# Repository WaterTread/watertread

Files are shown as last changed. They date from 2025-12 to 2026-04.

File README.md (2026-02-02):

# WaterTread



WaterTread is an open, tread-based hydrodynamic energy conversion system designed to harvest kinetic energy from flowing water using a controlled, blade-driven linear motion instead of a traditional rotating turbine.

The system is optimized for low- to moderate-flow environments and emphasizes simplicity, scalability, and containerized deployment.

[See 3D-model](https://watertreadweb.vercel.app/)

---

## Concept Overview

Unlike conventional hydrokinetic turbines, WaterTread uses a dual-tread mechanism with actively oriented blades that engage the water flow over an extended linear capture path.

Key principles:

- Multiple blades are engaged simultaneously
- Blades operate in alternating high-drag (capture) and low-drag (return) states
- Motion is driven purely by hydrodynamic forces
- Torque delivery is smooth and continuous
- Mechanical simplicity enables modular scaling

This approach reduces return-path losses and improves blade utilization compared to point-based rotating systems.

---

## Key Features

- Linear tread-based energy capture (non-rotor design)
- Actively controlled blade orientation using cams and followers
- High torque output at low flow velocities
- Low-drag, protected return path
- Modular and scalable architecture
- Designed to fit within standard ISO shipping containers
- Suitable for rivers, channels, and low-head flow environments

---

## Repository Structure

```
docs/                 Technical documentation (GitHub Pages)
models/               3D models and mechanical designs
  - prototype/        Early prototype models
  - 1.0/              Versioned production-ready designs
parts/                Parts lists and component specifications
images/               Diagrams, renders, and reference images
LICENSE               Non-commercial open license
COMMERCIAL.md         Commercial licensing terms
README.md             This file
```

---

## Licensing

### Non-Commercial Use

This project is released under the Creative Commons Attribution–NonCommercial–ShareAlike 4.0 (CC BY-NC-SA 4.0) license.

You are free to:

- Study and experiment with the design
- Build non-commercial prototypes
- Modify and improve the design
- Share derivative works under the same license

Commercial use is not permitted under this license.

---

### Commercial Use

Any commercial use — including manufacturing, deployment for power generation, or integration into commercial products — requires a separate license.

Commercial licensing is intentionally designed to be flexible, accessible, and affordable.

Royalty-based licenses are expected to be modest and competitive, often capped around approximately 1% of generated revenue, depending on project scope.

See [COMMERCIAL.md](COMMERCIAL.md) for details.

---

## Project Status

WaterTread is currently in an active design and prototyping phase.

- Mechanical concepts validated at prototype scale
- Detailed component documentation in progress
- Versioned 3D models under development
- Contributions and feedback are welcome

---

## Contributing

Contributions are welcome in the form of:

- Design feedback and reviews
- Mechanical or hydrodynamic improvements
- Simulation and analysis
- Documentation improvements
- Prototype testing insights

Please respect the non-commercial license terms when contributing.

---

## Disclaimer

This project is provided as-is, without warranty of any kind.
The author assumes no liability for the use, modification, or deployment of the design.

---

## Contact

For questions, collaboration, or commercial licensing inquiries:

Project Maintainer:
Keijo Mukku
keijo.mukku@gmail.com

Early-stage pilots, research collaborations, and first commercial deployments are especially welcome.

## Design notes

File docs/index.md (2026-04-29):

# WaterTread Documentation



Welcome to the WaterTread technical documentation.

WaterTread is an experimental open-flow hydrokinetic energy harvester concept designed to explore whether a staggered, three-dimensional moving blade field can extract useful energy from shallow flowing water without requiring a dam, closed pipe, or highly obstructive channel.

This documentation describes the operating principles, mechanical design, hydrodynamic assumptions, system-level behavior, and key validation questions behind the WaterTread concept.

## Contents

- [Project Considerations](considerations.md)
- [Hydrodynamic Operating Principle](hydrodynamics.md)
- [Blade Motion Cycle](blade_motion_cycle.md)
- [Power Transmission Overview](power_transmission.md)
- [System Efficiency Considerations](efficiency.md)
- [Profitability and ROI](profitability.md)

## Recommended Reading Order

If you are new to the project, start with:

1. [Project Considerations](considerations.md)  
   Defines the core hypothesis, engineering assumptions, risks, validation criteria, and early stop conditions.

2. [Hydrodynamic Operating Principle](hydrodynamics.md)  
   Explains how WaterTread is intended to interact with open-channel water flow.

3. [Blade Motion Cycle](blade_motion_cycle.md)  
   Describes the capture and return phases of the blade movement, including the low-drag return orientation.

4. [System Efficiency Considerations](efficiency.md)  
   Discusses the main factors that affect net power, including return drag, wake interaction, mechanical losses, and flow blockage.

For detailed component documentation, see the [`/parts`](../parts) directory.

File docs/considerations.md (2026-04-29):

# WaterTread Considerations

This document captures the current engineering reasoning, hypotheses, risks, validation needs, and development strategy for the WaterTread concept.

WaterTread is an early-stage hydrokinetic energy harvesting concept. It is not yet claimed to be more efficient than conventional hydrokinetic turbines, nor is it claimed to be commercially viable. The purpose of this document is to define what must be true for the concept to be worth continued development, and how those assumptions can be tested.

---

## 1. Core idea

WaterTread is an open-flow hydrokinetic energy harvester concept intended to extract useful energy from moving water without using a dam, closed pipe, or strongly obstructive channel.

The concept uses a moving tread-like mechanism carrying multiple blades. In the power-producing portion of the cycle, the blades present a large face to the water flow. In the return portion of the cycle, the blades rotate or travel edge-on to the flow, reducing return drag.

A key distinction from simple drag devices is that the blades are not merely arranged as a single flat row. The WaterTread concept aims to form a staggered, three-dimensional blade field, where partially overlapping blades interact with the flow across width, height, and depth.

The central design question is:

> Can a staggered, three-dimensional moving blade field extract useful net power from shallow open-channel flow while keeping return drag, blockage, ecological disruption, and mechanical losses acceptably low?

---

## 2. Core hypothesis

The central hypothesis is:

> Partially overlapping blades, arranged in a three-dimensional moving field, can interact with a larger shallow-flow volume than a single rotor disk or single flat blade, while returning edge-on to the flow to minimize return drag.

A more detailed version:

> A staggered 3D blade field may be able to produce higher useful force in shallow, wide, open flows by allowing multiple blades to engage different portions of the incoming flow, rather than forcing all energy extraction through a single circular rotor disk or a single flat capture surface.

This hypothesis is especially relevant to shallow and wide water flows, where conventional propeller-style or axial-flow rotors may be limited by available depth, rotor diameter, safety, debris, and ecological concerns.

---

## 3. What WaterTread is not yet claiming

WaterTread should not currently claim:

- that it is universally more efficient than hydrokinetic turbines;
- that it can exceed known physical limits for open-flow energy extraction;
- that it can collect energy without affecting the flow;
- that length alone creates additional free energy;
- that CFD, AI, or geometry generation alone can validate the concept;
- that the concept is commercially viable before physical or numerical validation.

A better and more defensible claim is:

> WaterTread explores whether a slow-moving, staggered, three-dimensional blade field can provide useful net power in shallow open-flow environments where conventional rotors may be limited by depth, safety, debris, maintenance, or ecological concerns.

---

## 4. Why not dams?

Dams are highly effective at extracting energy from water because they create hydraulic head: a difference in water height and pressure. This allows large amounts of gravitational potential energy to be converted into controlled high-power flow through turbines.

However, dams can cause major ecological and social impacts, including:

- blocked fish migration;
- altered sediment transport;
- changed river temperature and oxygen dynamics;
- disrupted seasonal flow patterns;
- habitat fragmentation;
- flooding of upstream land;
- significant permitting and infrastructure burden.

WaterTread is not intended to compete with the raw efficiency of large dam-based hydropower. Instead, it belongs conceptually to the hydrokinetic category: extracting energy from naturally moving water without requiring major hydraulic head, impoundment, or river closure.

The challenge is that hydrokinetic devices usually have much lower available energy density than dam-based systems.

---

## 5. Open-flow energy limitation

In open-flow systems, energy is extracted from the kinetic energy of moving water.

A useful first-order estimate of available kinetic power is:

```text
P_available ≈ 0.5 × rho × A × v^3
```

Where:

- `rho` is water density, approximately 1000 kg/m³;
- `A` is the effective flow area interacting with the device;
- `v` is the water velocity.

The velocity term is cubed. This means water speed is extremely important.

Example:

```text
A = 0.1 m²

v = 0.5 m/s  →  P_available ≈ 6.25 W
v = 1.0 m/s  →  P_available ≈ 50 W
v = 2.0 m/s  →  P_available ≈ 400 W
```

These values are before conversion losses. Real electrical output would be lower.

This means slow water contains surprisingly little useful power unless the device interacts with a large enough flow area or is placed in sufficiently fast current.

---

## 6. Important physical truth

If a device extracts energy from flowing water, it must affect the flow.

A completely invisible, zero-obstruction device cannot extract energy. Energy extraction requires changing the water's momentum, pressure field, or velocity field.

Therefore, the goal is not:

> Extract energy without affecting the flow at all.

The realistic goal is:

> Extract useful energy while minimizing harmful obstruction, ecological disruption, turbulence, debris accumulation, and flow blockage.

A better optimization target may be:

```text
maximize useful net power per ecological disturbance
```

or:

```text
maximize net power per blocked flow area
```

rather than simply maximizing raw power.

---

## 7. Comparison against rotors

Conventional hydrokinetic rotors are strong competitors. A well-designed lift-based rotor can be highly efficient because its blades can continuously produce useful torque without a separate return stroke.

This is an important difference:

```text
Rotor:
  - lift-based
  - blades can produce useful torque throughout rotation
  - no separate high-drag return side
  - mechanically compact
  - often efficient per swept area

Drag/tread device:
  - typically requires a power side and a return side
  - must minimize return drag
  - can suffer from mechanical complexity
  - may be less efficient per swept area
```

WaterTread's possible advantage is not necessarily pure hydrodynamic efficiency. Its stronger possible niche is:

- shallow water;
- wide but low-depth flow;
- slow and visible moving parts;
- easier access and maintenance;
- modular layout;
- potentially lower fish-strike risk than fast rotor tips;
- better use of a rectangular shallow flow envelope;
- less need for a deep circular swept area.

A fair comparison should not be WaterTread versus one arbitrary small rotor. It should be:

> WaterTread versus the best realistic rotor or multi-rotor arrangement that fits the same width, height, depth, blockage, ecological, and cost constraints.

---

## 8. Proposed advantage over rotor-like structures

A rotor collects energy from a swept disk area. Mechanically, it is compact and local in the stream.

WaterTread may instead distribute energy extraction across a longer and more volumetric interaction region.

The proposed advantage is:

> WaterTread may use a staggered 3D blade field to interact with a shallow flow volume across width, height, and depth, instead of requiring a deep circular rotor disk.

This may be beneficial where the available flow is:

- shallow;
- wide;
- debris-prone;
- ecologically sensitive;
- unsuitable for large-diameter rotors;
- better served by a slow-moving, modular, serviceable mechanism.

However, the fact that the device is longer in the flow direction does not automatically mean it accesses proportionally more energy. The key question is whether rear or overlapping blades receive sufficiently fresh flow, or whether they are mostly shadowed by the wake of upstream blades.

---

## 9. Staggered 3D blade field hypothesis

The most important WaterTread-specific hypothesis is not merely that the device is long.

The stronger hypothesis is:

> A staggered and partially overlapping blade field can reduce wake shadowing and allow multiple blades to extract energy from different portions of the flow volume.

This can be described as:

```text
3D staggered blade field
```

or:

```text
staggered volumetric blade array
```

Potential benefits:

- larger effective interaction volume;
- multiple blades in useful capture orientation at once;
- smoother force output;
- better use of shallow rectangular channels;
- possible reduction of peak local flow disturbance;
- slower and more visible motion than rotor tips.

Key risk:

> Upstream blades may still slow, deflect, or turbulently disturb the flow so much that downstream blades contribute little net power.

This must be tested.

---

## 10. Return drag hypothesis

A major improvement over many drag-based systems is the return orientation.

If the WaterTread blades return edge-on to the flow, arranged in sequence with minimal projected area, return drag may be small compared with capture drag.

This is critical.

The concept is much more promising if:

```text
F_return < 20–30% of F_capture
```

Where:

- `F_capture` is the force on blades in the power-producing orientation;
- `F_return` is the force on blades in the return orientation.

If return drag is too high, the mechanism may consume much of the energy it captures.

A useful early success criterion:

```text
F_capture / F_return >= 3
```

A stronger result:

```text
F_capture / F_return >= 4
```

This would make the concept more interesting.

---

## 11. Optimization problem formulation

A possible formal design objective:

```text
Maximize P_net
```

Where:

```text
P_net = P_extracted - P_return_losses - P_mechanical_losses
```

For a drag/tread approximation:

```text
P_net ≈ (F_capture - F_return) × u_device - P_mechanical
```

Where:

- `F_capture` = useful hydrodynamic force during the capture phase;
- `F_return` = drag force during return;
- `u_device` = blade/tread motion speed;
- `P_mechanical` = losses from pivots, bearings, chain, gears, generator, and control mechanism.

A more complete design goal:

```text
Maximize useful net power
subject to ecological, geometric, hydraulic, and manufacturability constraints.
```

---

## 12. Constraints

Possible design constraints:

```text
flow velocity = v
device width <= W
device height <= H
device length <= L
blocked flow area <= X%
return drag <= Y% of capture force
manufacturable geometry
acceptable maintenance burden
acceptable debris behavior
acceptable fish passage
open river flow preserved
no closed pipe
no dam-like obstruction
```

Additional constraints may include:

- maximum allowable upstream water level increase;
- maximum local acceleration near fish passage zones;
- minimum open bypass area;
- minimum gap size for fish/debris passage;
- maximum blade speed;
- maximum blade edge speed;
- maximum pressure drop;
- maximum turbulence intensity in bypass regions;
- corrosion and biofouling tolerance;
- safe failure mode.

---

## 13. Suggested performance metrics

Raw power is not enough.

Useful metrics include:

```text
P_net
P_net / A_blocked
P_net / device volume
P_net / material mass
P_net / cost
F_capture / F_return
rear-blade force retention
blockage ratio
wake recovery distance
maintenance burden
debris tolerance
fish interaction risk
```

Especially important early metrics:

```text
F_capture
F_return
F_capture / F_return
F_total for staggered blade field
F_total for inline blade field
rear blade force retention
```

---

## 14. Key risks

### 14.1 Wake shadowing

Rear blades may be in the wake of upstream blades and receive reduced flow velocity. Since power scales with velocity cubed, even modest reductions in local velocity can greatly reduce available power.

Question:

> Do staggered rear blades receive meaningful fresh flow, or mostly slowed and turbulent wake?

### 14.2 Mechanical losses

WaterTread has more mechanical complexity than a single-axis rotor.

Potential losses and issues:

- chain friction;
- pivot friction;
- bearing losses;
- gear losses;
- blade-angle control losses;
- sealing issues;
- misalignment;
- corrosion;
- biofouling;
- sediment wear;
- debris jamming;
- maintenance burden.

The mechanism must produce enough hydrodynamic gain to justify this complexity.

### 14.3 Return drag

Even if blades are edge-on during return, real-world return drag may not be negligible due to:

- blade thickness;
- support arms;
- turbulence;
- misalignment;
- sidewash;
- pivots and frames;
- water trapped between blades;
- imperfect orientation during transitions.

### 14.4 Obstruction and ecological impact

If blade density, side panels, or flow diverters become too aggressive, the device may behave like a partial obstruction or low-head barrier.

That could undermine the ecological motivation.

### 14.5 Competitor simplicity

A set of small slow rotors, Darrieus turbines, Archimedes screws, or other fish-friendly hydrokinetic devices may deliver similar or better performance with simpler mechanics.

WaterTread must prove a niche advantage, not just functionality.

---

## 15. Market positioning hypothesis

WaterTread should not initially position itself as a universal replacement for hydro turbines.

A more realistic niche hypothesis:

> WaterTread may be useful in shallow, wide, open-channel flows where conventional rotors are limited by water depth, debris, safety, fish interaction, maintenance access, or installation constraints.

Possible use cases:

- shallow irrigation channels;
- low-depth streams;
- industrial outflow channels;
- remote off-grid sites;
- educational and research demonstrators;
- modular river-edge installations;
- locations where deep rotors are impractical;
- locations where slow visible motion is preferred.

Potential value proposition:

```text
moderate energy output
+ low obstruction
+ shallow-water compatibility
+ maintainability
+ modularity
+ ecological sensitivity
```

rather than:

```text
maximum possible efficiency
```

---

## 16. Go / no-go criteria

The project is worth continued development if low-cost tests show that:

1. Return drag is less than 20–30% of capture drag.
2. A staggered blade arrangement produces significantly more force than an inline arrangement using the same blade area.
3. Rear blades retain meaningful force and are not fully shadowed by upstream blades.
4. The mechanism can move under load without excessive friction or jamming.
5. Useful net power can be produced without blocking an unacceptable portion of the flow.
6. A simple benchmark rotor or drag device does not clearly dominate under the same envelope constraints.
7. The design appears maintainable in debris-prone water.

Possible early stop criteria:

1. Return drag is more than 20-30% of capture drag.
2. Rear blades contribute little additional force.
3. Mechanical friction is comparable to or larger than hydrodynamic net force.
4. The device only works when it significantly blocks or channels the flow.
5. A simple rotor or paddle wheel produces much better power with less complexity in the same test conditions.

---

## 17. Low-cost validation plan

The first validation step should not be full CFD or a complete generator prototype.

The first step should be a simple force measurement.

### 17.1 Single blade test

Measure:

```text
F_capture_single
F_return_single
```

Using:

- one test blade;
- a rod or frame;
- a fish scale or luggage scale;
- flowing water or a controlled pull through still water.

Test orientations:

```text
capture position: broad face to flow
return position: edge-on to flow
```

Record:

- blade dimensions;
- water speed or pull speed;
- force reading;
- blade angle;
- depth;
- repeatability.

### 17.2 Inline versus staggered test

Build three static blade arrangements:

```text
A: single blade
B: three blades inline
C: three blades staggered / overlapping like WaterTread
```

Compare total force under the same flow speed.

Key question:

```text
Does the staggered arrangement outperform the inline arrangement?
```

### 17.3 Rear-blade shadowing test

Measure force on a rear blade with and without upstream blades present.

Important metric:

```text
rear_blade_retention = F_rear_with_front_blades / F_single_blade
```

If this value is high, staggered geometry may be working.

If it is low, wake shadowing may dominate.

### 17.4 Return-array test

Arrange several blades in the return orientation, edge-on to the flow.

Measure total return drag.

Compare:

```text
F_capture_array / F_return_array
```

### 17.5 Simple moving mechanism test

Only after static force tests are promising, build a simple moving prototype.

It should answer:

- Does it move under water load?
- Does it stall?
- Does the return side behave as expected?
- How much mechanical friction is present?
- Can it lift a small weight or drive a simple generator under load?

---

## 18. Fish scale measurement concept

A fish scale does not measure the blade directly. It measures force.

Basic setup:

```text
water flow → blade → rod/string → fish scale → fixed point
```

The water pushes on the blade. The blade pulls on the scale. The scale reading gives the force required to hold the blade in place.

If the scale reads in kilograms-force:

```text
1 kgf ≈ 9.81 N
```

Example:

```text
capture reading = 1.2 kgf ≈ 11.8 N
return reading  = 0.25 kgf ≈ 2.5 N

force ratio = 11.8 / 2.5 ≈ 4.7
```

This would be promising for return drag reduction.

The scale must be aligned with the flow direction, and the blade angle must be held constant. A rigid rod or frame is better than a loose string if the blade tends to rotate.

---

## 19. Role of CFD

CFD may be useful, but it should not be the first validation step and should not initially attempt to simulate the full moving mechanism.

The first useful CFD study should be a simplified static comparison:

```text
1. single blade
2. inline blade array
3. staggered blade array
4. return-position blade array
```

Suggested CFD outputs:

- drag force per blade;
- total drag force;
- pressure field;
- velocity field;
- wake / shadowing behavior;
- turbulence / vorticity;
- blockage estimate;
- capture-to-return force ratio.

Suggested initial CFD setup:

```text
flow: incompressible water
solver type: steady-state RANS
turbulence model: k-omega SST
geometry: simplified blades in open rectangular channel
velocities: e.g. 0.5, 1.0, 1.5 m/s
```

Full transient moving-mesh CFD should come later, if simplified tests are promising.

---

## 20. Role of PicoGK

PicoGK may be useful later as a parametric geometry generator.

It is not a CFD solver and should not be treated as a validation tool.

Potential PicoGK uses:

- blade shape variants;
- blade curvature;
- staggered blade-field arrangements;
- flow diverters;
- side panels;
- return-flow shielding;
- simplified CFD-ready fluid domains;
- rapid generation of geometry variants.

A possible future workflow:

```text
parameters → PicoGK geometry → CFD or physical test → performance metrics → optimization → new parameters
```

PicoGK becomes more useful once the project has identified which geometric variables matter.

---

## 21. Role of AI

AI is not useful as a substitute for validation at this stage.

AI may become useful later as a surrogate model or optimization assistant after enough data exists.

Possible future workflow:

```text
1. Generate many geometry variants.
2. Simulate or physically test them.
3. Collect performance data.
4. Train an AI/surrogate model.
5. Use the model to explore the design space.
6. Validate the best candidates with real tests or CFD.
```

Without data, AI is mostly guessing.

---

## 22. Important benchmark comparisons

WaterTread should be compared against simple alternatives.

Suggested benchmarks:

1. Single flat plate.
2. Simple paddle wheel.
3. Small axial-flow rotor.
4. Small vertical-axis/Darrieus-type rotor.
5. Multiple small rotors in the same width-height-length envelope.
6. Static drag array with no moving return side.

Benchmark constraints should be equal:

```text
same flow speed
same width W
same height H
same allowed length L
same blockage limit
same environmental constraints
same measurement method
```

The question should not be:

> Does WaterTread produce power?

The better question is:

> Does WaterTread produce enough net power, with enough ecological and practical advantage, to justify its added mechanical complexity?

---

## 23. Development philosophy

The correct current stage is not optimization.

The correct current stage is falsification.

The project should try to quickly and cheaply discover whether the core idea is promising.

Recommended philosophy:

```text
Build the smallest possible test.
Measure the most important assumption.
Compare against the simplest alternative.
Stop or pivot early if the numbers are weak.
Only optimize after the basic effect is proven.
```

Avoid spending significant time on:

- full product design;
- advanced CFD;
- AI optimization;
- detailed generator integration;
- complex manufacturing;
- marketing claims;

before the force and return-drag fundamentals are measured.

---

## 24. Suggested first milestone

A strong first milestone would be:

```text
Demonstrate that a staggered 3D blade arrangement produces significantly higher useful force than an inline arrangement, while the return orientation produces less than 20–30% of capture drag.
```

Minimum measurement set:

```text
F_capture_single
F_return_single
F_capture_inline_array
F_capture_staggered_array
F_return_array
water_speed_or_pull_speed
blade_geometry
blade_angles
```

A promising result might look like:

```text
F_capture_single = 5 N
F_return_single = 1 N
F_capture_staggered_array = 12 N
F_return_array = 2.5 N
```

This would suggest:

```text
single blade ratio = 5:1
array ratio = 4.8:1
staggered array adds useful force
```

Such a result would justify further work.

---

## 25. Suggested second milestone

After static testing, build a minimal moving prototype.

Goal:

> Demonstrate continuous motion under water load while doing measurable mechanical work.

Possible simple outputs:

- lifting a small weight;
- turning a small DC motor as a generator;
- driving a friction brake;
- measuring torque and speed at an output shaft.

Useful measurements:

```text
shaft torque
shaft speed
mechanical output power
flow velocity
device dimensions
estimated blockage
qualitative debris behavior
```

Power estimate:

```text
P_mechanical = torque × angular_velocity
```

or, for linear force:

```text
P_mechanical = force × velocity
```

---

## 26. Current best project narrative

A strong project description could be:

> WaterTread is an experimental open-flow hydrokinetic energy harvester designed for shallow, wide, and ecologically sensitive water flows. It uses a staggered three-dimensional blade field to interact with a larger shallow-flow volume than a single rotor disk, while returning the blades edge-on to the flow to minimize return drag. The project is currently focused on validating whether this geometry can produce useful net power without unacceptable flow obstruction or mechanical complexity.

---

## 27. Open research questions

Key unanswered questions:

1. How much of the apparent 3D flow volume is actually usable before wake shadowing dominates?
2. What is the true capture-to-return drag ratio?
3. How much net mechanical power remains after chain, pivot, bearing, and generator losses?
4. What blade spacing and overlap maximize useful force without excessive blockage?
5. How does the device compare to a rotor or multi-rotor array in the same envelope?
6. Can the device tolerate debris, sediment, vegetation, and biofouling?
7. Can fish and other aquatic life safely pass around or through the system?
8. Does the flow diverter help enough to justify its obstruction?
9. Can the mechanism be made simple and robust enough for real water environments?
10. Is the best market niche energy output, ecological compatibility, shallow-water operation, maintainability, or some combination?

---

## 28. Summary

WaterTread is not yet proven, but it is not obviously a waste of time.

The concept contains a testable and potentially interesting hypothesis:

> A staggered, three-dimensional blade field with low-drag edge-on return may offer a practical way to harvest energy from shallow open-channel flows where conventional rotors are constrained.

The project should continue only through disciplined validation.

The next step is not advanced simulation or full product development. The next step is simple force testing:

```text
capture force
return force
inline versus staggered array
rear-blade shadowing
basic mechanical losses
```

If those tests are promising, the project deserves further CFD, prototyping, and optimization.

If those tests are weak, the concept should be modified or stopped before significant resources are spent.

The strongest current position is:

> WaterTread is a serious hypothesis worth testing, not yet a proven machine.

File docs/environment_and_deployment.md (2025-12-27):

# Environmental Compatibility and Deployment Options

This document highlights two key characteristics of the WaterTread system that differentiate it from conventional hydropower solutions:
environmental friendliness and flexible deployment configurations.

---

## 1. Environmentally Friendly Operation

### Fish Migration and Ecosystem Compatibility

WaterTread is designed as a **non-blocking, open-flow energy system**.
Unlike conventional dams or weirs, it does not create a full barrier across a river or channel.

Key environmental advantages:

- **Allows fish migration**  
  The system does not obstruct upstream or downstream movement of fish and aquatic organisms.
  Flow paths remain open around and through the installation.

- **No reservoir formation**  
  WaterTread does not require impoundment or large changes to water level.

- **Low-pressure operation**  
  Energy is extracted from kinetic flow rather than head height, reducing stress on ecosystems.

- **Reduced ecological footprint**  
  Minimal civil works compared to traditional hydro infrastructure.

This makes WaterTread suitable for environmentally sensitive locations where conventional hydro solutions are not acceptable.

---

## 2. Flexible Deployment Configurations

WaterTread is designed to operate in multiple physical orientations and mounting configurations,
allowing adaptation to diverse site conditions.

### 2.1 Floating Installation (Suspended)

- Mounted beneath a floating structure or pontoon
- The system hangs below the water surface
- Particularly suitable for locations with:
  - High debris load (branches, ice, vegetation)
  - Variable water levels
- Floating debris passes above the system, reducing clogging risk
- Installation and maintenance can be performed from the surface

### 2.2 Vertical Bottom-Mounted Installation

- System is mounted vertically to the riverbed or channel floor
- Suitable for deeper channels with stable flow
- Compact footprint and clear separation of capture and return paths
- Maintains open flow above the installation

### 2.3 Horizontal Bottom-Mounted Installation

- System is mounted horizontally on the riverbed
- Two WaterTread units may be installed facing each other
- This configuration:
  - Forms a converging flow channel
  - Increases local water velocity and pressure
  - Enhances energy capture without full blockage

Such paired installations act as **flow-directing structures** rather than dams.

---

## Design Implications

- Deployment flexibility reduces site preparation costs
- Orientation can be selected based on:
  - Debris load
  - Flow depth
  - Seasonal variation
- Multiple configurations allow modular scaling

---

## Summary

WaterTread combines:
- **Fish-friendly, non-blocking operation**
- **Adaptable installation methods**
- **Minimal environmental impact**

These characteristics position WaterTread as a practical solution for locations where traditional hydropower is unsuitable due to environmental or regulatory constraints.

---

## Related Documents

- `docs/hydrodynamics.md`
- `docs/efficiency.md`
- `docs/profitability.md`

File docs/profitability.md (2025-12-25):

# Profitability and ROI Considerations

This document outlines a simplified approach for evaluating the economic viability of the WaterTread system.
The goal is not to provide exact financial forecasts, but to define reasonable cost boundaries based on energy production and electricity pricing.

---

## Key Variables

The profitability of a WaterTread installation depends on the following primary variables:

- **P** = Average electrical power output (kW)
- **H** = Annual operating hours (hours/year)
- **E** = Annual energy production (kWh/year)
- **Cₑ** = Electricity price (€/kWh or $/kWh)
- **R** = Annual revenue from electricity (€/year or $/year)
- **Cₛ** = Total system cost (including installation)
- **T** = Target payback period (years)

---

## Energy Production

Annual energy production is calculated as:

E = P × H

Example:
- Average power output: 1.5 kW
- Operating time: 6,000 hours/year

E = 1.5 × 6,000 = 9,000 kWh/year

---

## Annual Revenue

Annual revenue from electricity generation:

R = E × Cₑ

Example electricity prices:
- Low: 0.05 €/kWh (industrial / wholesale)
- Medium: 0.15 €/kWh (typical grid price)
- High: 0.30 €/kWh (remote or off-grid)

Example (0.15 €/kWh):
R = 9,000 × 0.15 = 1,350 €/year

---

## Cost Boundary Based on Payback Time

A simple and practical profitability rule:

Cₛ ≤ R × T

Where **T** is the acceptable payback period.

Typical target payback periods:
- Aggressive: 3–5 years
- Moderate: 6–10 years
- Conservative infrastructure: 10–15 years

Example (T = 8 years):
Cₛ ≤ 1,350 × 8 = 10,800 €

This means the fully installed system should cost **no more than ~10,000–11,000 €** to be economically attractive at this power level and electricity price.

---

## Sensitivity to Power Output

Because revenue scales linearly with power:

- Doubling average power output doubles annual revenue
- Increasing effective blade area or flow velocity has a direct economic impact
- Distributed capture (multiple blades engaged simultaneously) is economically advantageous

---

## Comparison to Other Small-Scale Hydro Systems

WaterTread targets applications where:
- Conventional turbines are inefficient or impractical
- Flow velocities are moderate but continuous
- Maintenance simplicity and debris tolerance are critical

In such environments, slightly lower peak efficiency may be acceptable if:
- Capital cost is low
- Reliability and uptime are high
- Installation is simple and modular

---

## Economic Design Implications

To remain commercially viable:
- Structural materials should be low-cost and durable
- Passive control (cams, guides) reduces operational expenses
- Container-sized systems reduce transport and installation costs
- Modular design enables incremental scaling

---

## Disclaimer

This document provides conceptual guidance only.
Actual profitability depends on site-specific conditions, regulatory environment, maintenance costs, and financing structure.

---

## Related Documents

- `docs/efficiency.md`
- `docs/hydrodynamics.md`
- `COMMERCIAL.md`

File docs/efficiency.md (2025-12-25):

# System Efficiency Considerations

WaterTread efficiency depends on several interacting factors:

- Effective blade area exposed to flow
- Water velocity and density
- Blade orientation control accuracy
- Flow confinement by hydrodynamic panels
- Mechanical transmission losses

Unlike rotor-based turbines, WaterTread minimizes counterproductive drag during the return phase. Energy capture occurs along a longer interaction path, potentially increasing total extracted energy for a given flow cross-section.

System efficiency is ultimately bounded by hydrodynamic limits, but distributed capture and passive control reduce losses commonly found in rotating systems.

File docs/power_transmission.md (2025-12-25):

# Power Transmission Overview

Mechanical energy captured by the blades is transferred into the tread system and delivered to the drivetrain.

Linear tread motion drives synchronized gears mounted on shared axles. These gears convert linear motion into rotation, which is then stepped up via a pinion to reach generator-compatible speeds.

The drivetrain prioritizes simplicity, low friction, and passive synchronization. Spring-loaded rear axle mounts maintain tread tension without introducing additional idler gears or parasitic losses.

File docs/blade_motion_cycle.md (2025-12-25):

# Blade Motion Cycle (Capture → Transition → Return)

Each blade follows a repeating motion cycle:

## Capture Phase
The blade is rotated into a vertical, high-drag orientation by the cam and cam follower. Hydrodynamic force acting on the blade drives the tread system forward.

## Transition Phase
As the blade exits the capture region, the cam profile releases the cam follower, allowing the blade to rotate freely.

## Return Phase
The blade is guided into a low-drag orientation by the return guide and water flow, allowing it to travel upstream with minimal resistance.

This cyclical behavior enables continuous directional motion driven purely by hydrodynamic forces.

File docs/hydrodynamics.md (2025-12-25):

# Hydrodynamic Operating Principle

WaterTread converts the kinetic energy of flowing water into mechanical motion using a tread-based blade system.

Unlike conventional turbines, WaterTread distributes energy capture along a linear path. Multiple blades engage the flow simultaneously, creating a continuous force application rather than a point-based interaction.

Fixed hydrodynamic side and center panels confine the flow, preventing lateral and vertical escape and directing water through the blade capture region. This controlled channel maximizes usable hydrodynamic force while minimizing losses.

Blades alternate between a high-drag capture state and a low-drag return state, ensuring that only productive surfaces interact with the flow.

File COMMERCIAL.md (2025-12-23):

# Commercial Licensing

The WaterTread technology is published as an open project to encourage research, experimentation, and non-commercial development.

Non-commercial use is permitted under the Creative Commons Attribution–NonCommercial–ShareAlike 4.0 (CC BY-NC-SA 4.0) license.

Any commercial use requires a separate commercial license agreement.

---

## What Counts as Commercial Use

Commercial use includes, but is not limited to:

- Manufacturing products based on this design for sale
- Selling or monetizing electricity generated using the system
- Deploying the system as part of a commercial service or offering
- Integrating the design into proprietary or commercial products
- Using the design in revenue-generating pilot or demonstration projects

If you are unsure whether your use case is considered commercial, please get in touch.

---

## Commercial Licensing Philosophy

Commercial licensing for this project is intentionally designed to be:

- Flexible
- Accessible
- Affordable

The goal is to enable real-world deployment and experimentation without creating unnecessary financial or legal barriers.

---

## Licensing Models

Commercial licenses are negotiated on a case-by-case basis and may include one or more of the following models:

- Revenue-based royalties
- Fixed annual licenses
- Per-installation or per-project licenses
- Hybrid models combining royalties and fixed fees
- Optional regional or application-specific exclusivity

As a general guideline, royalty-based licenses are expected to be modest and competitive. In many cases, royalties may be capped at approximately 1% of generated revenue, depending on the scope, scale, and maturity of the deployment.

Exact terms are always agreed separately and documented in a written license agreement.

---

## What a Commercial License Provides

A commercial license may include:

- Permission to manufacture and deploy commercial systems
- Permission to sell electricity or services based on the system
- Legal clarity for investors, partners, and customers
- Access to future design updates (optional)
- Technical collaboration or support (optional)
- Recognition as an official licensee (optional)

---

## Intellectual Property Notice

This project is not patented. The value of the commercial license lies in:

- Clear permission to use the design commercially
- Documented authorship and provenance
- Access to an actively developed, versioned design
- Reduced legal and reputational risk compared to unlicensed use

---

## Contact

For commercial licensing inquiries, discussions, or pilot projects, please contact:

Project Maintainer:
Keijo Mukku
keijo.mukku@gmail.com

Early-stage pilots, research collaborations, and first commercial deployments are especially welcome.

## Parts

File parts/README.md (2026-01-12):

# Parts Overview

This section documents the mechanical and structural components of the WaterTread system.

The parts listed here describe the **concept-level design** and functional interfaces of each component.  
Concrete, version-specific implementations of these parts are located under the `models/` directory.

---

## How This Section Is Organized

- Each part has its own directory under `parts/`
- Each part directory contains a `README.md` describing:
  - The function of the part
  - Interfaces to other components
  - Quantities used in the system
  - Notes relevant across versions
- Version-specific geometry, dimensions, and manufacturing files are stored under:
  - `models/prototype/parts/`
  - `models/1.0/parts/`
  - future version directories as applicable

This separation keeps the conceptual design stable while allowing implementations to evolve between system versions.

---

## Parts Index

1. [Axle](axle/)
2. [Blade](blade/)
3. [Cam](cam/)
4. [Cam Follower](cam_follower/)
5. [Center Panel](center_panel/)
6. [Flow Diverter](flow_diverter/)
7. [Frame](frame/)
8. [Front Axle Mount](front_axle_mount/)
9. [Gear](gear/)
10. [Generator](generator/)
11. [Link Tread](link_tread/)
12. [Link Tread Connector](link_tread_connector/)
13. [Pinion](pinion/)
14. [Rear Axle Mount](rear_axle_mount/)
15. [Return Guide](return_guide/)
16. [Side Panel](side_panel/)

---

## Versioning Policy

Parts in this directory are **not individually versioned**.

Instead:
- The WaterTread system is versioned as a whole (e.g. Prototype, v1.0, v2.0)
- Any dimensional or structural change to a part is reflected by a new system version
- Concept-level descriptions in `parts/` remain valid across versions unless explicitly stated

See `models/` for version-specific implementations.

---

## Units and Conventions

- Linear dimensions may be expressed in LEGO units (L) for prototype reference
- Production models use metric units (mm)
- Coordinate systems and orientation are defined relative to the direction of water flow

Additional shared conventions may be documented in a future `COMMON.md` file.

---

## Licensing Note

The part descriptions and associated files are provided for non-commercial use under the CC BY-NC-SA 4.0 license.

Commercial use of any part or system implementation requires a separate license.  
See the repository root `COMMERCIAL.md` for details.

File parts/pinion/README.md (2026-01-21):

# Pinion

[See 3D-model](./pinion.stl)

## Function

The pinion is a small drive gear that interfaces with the primary gear to increase rotational speed for the generator.
It adapts the relatively slow, high-torque motion of the tread system into a higher-speed rotation suitable for efficient electrical generation.

The pinion enables flexible gear ratio selection without altering the primary tread geometry.

---

## Quantity

1 pc per system (minimum configuration)

Additional pinions or generators may be added depending on system scaling and power requirements.

---

## Interfaces

- **Gear**
  - Pinion meshes with the primary gear
  - Gear ratio determines output speed and torque characteristics

- **Generator**
  - Pinion is mounted directly to the generator shaft or via a coupling
  - Transfers rotational motion into the generator input

- **Axle / Bearing Mount**
  - Pinion alignment is maintained by the generator mount or dedicated bearing support

---

## Reference Geometry

- Tooth count, pitch, and diameter are implementation-specific
- Pinion size is selected to achieve the desired speed increase
- Multiple gear ratios may be evaluated across system versions

---

## LEGO Reference Part (Prototype)

- **3647** Technic Gear 8 Tooth

Reference parts are used for prototyping only and do not constrain production geometry.

---

## Operating Role

- Increases rotational speed relative to the tread drive gear
- Allows the generator to operate closer to its optimal efficiency range
- Enables system tuning for different flow conditions and generator types

---

## Design Notes

- Smaller pinions increase speed but reduce torque margin
- Gear ratio selection balances efficiency, durability, and generator requirements
- Pinion may be replaced by alternative transmission elements in future versions (e.g. multi-stage gearing)

---

## Implementations

- Prototype implementation:
  `models/prototype/parts/pinion/`

- Production implementation (v1.0):
  `models/1.0/parts/pinion/`

---

## Licensing

This part is provided for non-commercial use under the
Creative Commons Attribution–NonCommercial–ShareAlike 4.0 (CC BY-NC-SA 4.0) license.

Commercial use requires a separate license.
See the repository root `COMMERCIAL.md` for details.

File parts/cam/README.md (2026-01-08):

# Cam

[See 3D-model](./cam.stl)

Tags: #static #kinematic #cam-mechanism #motion-shaping #tribological #friction-critical #wear-surface #structural #guide

## Function

The cam is a fixed, passive control element that defines the blade capture geometry and timing.
It engages with the cam followers during the capture phase to rotate and hold each blade in its high-drag orientation while it traverses the active energy capture region.

The cam operates without actuators or active control, relying solely on its geometric profile.

---

## Quantity

2 pcs per system (one per side)

---

## Interfaces

- **Cam Follower**

  - Cam followers ride along the cam profile during the capture phase
  - The cam profile determines blade orientation angle, timing, and dwell

- **Hydrodynamic Side Panel**

  - The cam is mounted to the inner surface of the hydrodynamic side panel
  - Side panel provides structural support and precise alignment

- **Frame**
  - Cam position is fixed relative to the frame to ensure repeatable blade motion

---

## Geometry Description

- The cam is a **partial cam rail**, active only along the capture path
- Outside the capture region, cam followers disengage freely
- Cam geometry is shaped to:
  - Rotate blades smoothly into vertical orientation
  - Maintain blade angle during peak loading
  - Release blades cleanly into the return phase

---

## Operating Role

- During the **capture phase**, the cam enforces blade orientation against hydrodynamic loads
- During the **transition phase**, the cam profile allows controlled release
- During the **return phase**, the cam does not interact with the cam follower

---

## Design Notes

- Cam profile is optimized to minimize impact loads and wear
- Passive geometry ensures inherent synchronization across all blades
- Fixed cam eliminates the need for sensors, controls, or actuators
- Cam shape may evolve between system versions while maintaining the same functional role

---

## Licensing

This part is provided for non-commercial use under the
Creative Commons Attribution–NonCommercial–ShareAlike 4.0 (CC BY-NC-SA 4.0) license.

Commercial use requires a separate license.
See the repository root `COMMERCIAL.md` for details.

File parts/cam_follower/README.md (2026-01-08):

# Cam Follower

[See 3D-model](./cam_follower.stl)

Tags: #moving #kinematic #motion-constrained #tribological #friction-critical #wear-surface #contact-surface #load-bearing

## Function

The cam follower interfaces between the blade and the cam, translating the cam profile into controlled blade rotation.
It ensures that each blade is guided into and held in its high-drag capture orientation during the power stroke, and released for reorientation during the return phase.

Cam followers enable precise, repeatable blade motion without requiring active control or actuators.

---

## Quantity

28 pcs per system

---

## Interfaces

- **Blade**

  - Each blade is connected to two cam followers, one at each end
  - Provides a rotational interface allowing the blade to pivot between operating states

- **Cam**

  - The cam follower rides along the cam profile during the capture phase
  - Contact geometry determines blade orientation and timing

- **Link Tread with Connector**
  - Cam follower is mounted to the tread system via a low-friction pin connection
  - Allows free rotation while transmitting linear motion

---

## LEGO Reference Parts

- [**7329** Technic Angle Connector 3-Way 60/120 Degrees](https://library.ldraw.org/parts/45842)
- [**22961** Technic Axle with Perpendicular Pin Hole](https://library.ldraw.org/parts/2013) (2 pcs)
- [**3673** Technic Pin without Friction Ridges](https://library.ldraw.org/parts/6706)

---

## Operating Role

- During the **capture phase**, the cam follower engages the cam and rotates the blade into its vertical, high-drag orientation
- While engaged, the cam follower maintains blade angle against hydrodynamic loads
- During the **return phase**, the cam follower disengages from the cam, allowing the blade to rotate freely into a low-drag configuration

---

## Design Notes

- Cam follower mass is minimized to reduce inertial losses
- Mechanical simplicity improves reliability in submerged operation
- Passive operation ensures synchronization across all blades

---

## Licensing

This part is provided for non-commercial use under the
Creative Commons Attribution–NonCommercial–ShareAlike 4.0 (CC BY-NC-SA 4.0) license.

Commercial use requires a separate license.
See the repository root `COMMERCIAL.md` for details.

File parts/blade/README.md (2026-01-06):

# Blade

[See 3D-model](./blade.stl)

## Function

The blade captures kinetic energy from flowing water and converts it into mechanical motion, which is transferred to the tread system via the cam follower and link tread.

Blade orientation is actively controlled, allowing it to alternate between a high-drag capture state and a low-drag return state.

---

## Quantity

14 pcs per system

---

## Dimensions (Reference)

- Height: **5L** (including one stud provided by the cam follower interface)
- Width: **20L**

Dimensions are expressed in LEGO units (L) for prototype reference.
Production dimensions are defined in the corresponding system version under `models/`.

---

## LEGO Reference Parts

- [**3705** Technic Axle 4](https://library.ldraw.org/parts/6762) (2 pcs)

---

## Modifications

- Create a cube mesh with size of 159x2x40 (slightly narrower than the cavity)
- Cut bottom corners to make room for **Link Tread with Connector** and **Cam Follower**
- Import two Technic Axles 4 to position 76/0/4 and -76/0/4

---

## Interfaces

- **Cam Follower**
  Blade is connected at both ends to cam followers, enabling controlled rotation between capture and return phases.

- **Link Tread with Connector**
  Blade mounting points align with perpendicular pin-hole connectors on the tread system.

---

## Operating States

- **Capture Phase**
  Blade is oriented vertically to maximize hydrodynamic drag and force transfer.

- **Return Phase**
  Blade is reoriented into a low-drag configuration to minimize resistance while moving upstream.

---

## Implementations

- Prototype implementation:
  `models/prototype/parts/blade/`

- Production implementation (v1.0):
  `models/1.0/parts/blade/`

---

## Licensing

This part is provided for non-commercial use under the
Creative Commons Attribution–NonCommercial–ShareAlike 4.0 (CC BY-NC-SA 4.0) license.

Commercial use requires a separate license.
See the repository root `COMMERCIAL.md` for details.

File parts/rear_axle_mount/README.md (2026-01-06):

# Rear Axle Mount

[See 3D-model](./rear_axle_mount.stl)

## Function

The rear axle mount supports the rear axle while allowing controlled axial movement to maintain proper tread tension.
It incorporates a spring-loaded mechanism that compensates for wear, thermal expansion, and load variations, ensuring consistent tread engagement and smooth operation.

Unlike the front axle mount, the rear axle mount is intentionally compliant.

---

## LEGO Technic reference part

- [Technic Shock Absorber 6.5L Soft](https://library.ldraw.org/parts/8118)
- [Technic Beam 3](https://library.ldraw.org/parts/1146)

---

## Quantity

2 pcs per system (one per side)

---

## Interfaces

- **Axle**

  - Supports the rear axle shaft
  - Allows limited axial displacement for tension adjustment

- **Frame**

  - Mount is connected to the frame via spring housings
  - Frame defines the allowable movement range

- **Gear**

  - Maintains correct gear meshing under varying load and tension conditions

- **Link Tread**
  - Indirectly maintains proper tread tension and alignment

---

## Reference Configuration

- Implemented as a spring-loaded pillow block bearing assembly
- Consists of:
  - A bearing block supporting the axle shaft
  - Integrated coil springs housed in tubular guides
- Springs bias the axle outward to maintain tread tension

---

## Operating Role

- Maintains consistent tread tension during operation
- Compensates for manufacturing tolerances and wear
- Reduces shock loads on the drivetrain during transient conditions

---

## Design Notes

- Spring stiffness should be selected to balance tension stability and mechanical losses
- Axial travel range is limited to prevent misalignment
- Bearing selection should consider submerged or splash-zone operation
- Symmetric mounts on both sides ensure even load distribution

---

## Implementations

- Prototype implementation:
  `models/prototype/parts/rear_axle_mount/`

- Production implementation (v1.0):
  `models/1.0/parts/rear_axle_mount/`

---

## Licensing

This part is provided for non-commercial use under the
Creative Commons Attribution–NonCommercial–ShareAlike 4.0 (CC BY-NC-SA 4.0) license.

Commercial use requires a separate license.
See the repository root `COMMERCIAL.md` for details.

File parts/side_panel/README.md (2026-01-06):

# Hydrodynamic Side Panel

[See 3D-model](./side_panel.stl)

## Function

The hydrodynamic side panel forms the lateral boundaries of the water flow channel around the blades.
It prevents lateral water escape, concentrates flow through the blade capture region, and improves overall hydrodynamic efficiency.

The side panels also serve as structural mounting surfaces for the cam elements.

---

## Quantity

2 pcs per system (left and right)

---

## Interfaces

- **Frame**

  - Side panels are rigidly mounted to the frame
  - Define the lateral geometry of the flow channel

- **Blades**

  - Blades operate within the channel formed between the side panels
  - Panels do not move with the blades, minimizing moving mass

- **Cam**

  - Cam elements are mounted to the inner surface of the side panels
  - Provides precise alignment for cam–follower interaction

- **Hydrodynamic Center Panel**
  - Side panels interface with the center panel to form a closed flow channel

---

## Geometry Description

- Panels follow the overall elliptical path of the tread system
- Geometry is shaped to:
  - Guide incoming flow toward the blade capture region
  - Minimize turbulence and leakage
  - Maintain consistent clearance to moving components

---

## Operating Role

- During the **capture phase**, side panels confine flow to maximize blade loading
- During the **return phase**, panels isolate the return path from incoming flow

---

## Design Notes

- Panels are fixed to reduce moving mass and inertial losses
- Structural stiffness is required to maintain cam alignment
- Panel geometry may evolve to optimize hydrodynamic performance
- Surface finish may influence flow behavior and efficiency

---

## Implementations

- Prototype implementation:
  `models/prototype/parts/side_panel/`

- Production implementation (v1.0):
  `models/1.0/parts/side_panel/`

---

## Licensing

This part is provided for non-commercial use under the
Creative Commons Attribution–NonCommercial–ShareAlike 4.0 (CC BY-NC-SA 4.0) license.

Commercial use requires a separate license.
See the repository root `COMMERCIAL.md` for details.

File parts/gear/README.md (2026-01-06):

# Gear

[See 3D-model](./gear.stl)

## Function

The gear converts linear motion from the tread system into rotational motion and forms the primary mechanical interface between the tread assemblies and the power transmission system.

Gears are used in synchronized pairs at the front and rear of the system to maintain alignment between the left and right tread paths while transmitting torque to the generator via a pinion.

---

## Quantity

4 pcs per system

---

## Interfaces

- **Link Tread**

  - The tread engages directly with the gear teeth
  - Linear tread motion is converted into rotational motion

- **Axle**

  - Each gear pair is mounted on a shared axle
  - Ensures synchronized rotation of parallel tread assemblies

- **Pinion**

  - Gear engages with a smaller pinion to increase rotational speed for the generator

- **Frame and Axle Mounts**
  - Gear alignment is maintained by the axle mounts fixed to the frame

---

## Reference Geometry

- Tooth count and pitch are implementation-specific
- Prototype implementations may use standard LEGO Technic gears
- Production versions may use custom gear geometries optimized for load, efficiency, and hydrodynamic conditions

---

## LEGO Reference Part (Prototype)

- [**3649** Technic Gear 40 Tooth](https://library.ldraw.org/parts/6673)

Reference parts are used for prototyping only and do not constrain production geometry.

---

## Modifications (Prototype)

- Remove non-functional through-holes and associated mounting features
- Retain the central axle interface and gear teeth
- Modification reduces unnecessary mass and minimizes hydrodynamic resistance when submerged

---

## Operating Role

- Transfers blade-generated forces from the tread system into rotational motion
- Provides smooth torque delivery to the generator
- Maintains synchronization between front and rear tread paths

---

## Design Notes

- Gear geometry may change between system versions without altering functional role
- Tooth profile, material, and size may be optimized for durability and efficiency
- Submerged operation favors reduced mass and minimized drag

---

## Implementations

- Prototype implementation:
  `models/prototype/parts/gear/`

- Production implementation (v1.0):
  `models/1.0/parts/gear/`

---

## Licensing

This part is provided for non-commercial use under the
Creative Commons Attribution–NonCommercial–ShareAlike 4.0 (CC BY-NC-SA 4.0) license.

Commercial use requires a separate license.
See the repository root `COMMERCIAL.md` for details.

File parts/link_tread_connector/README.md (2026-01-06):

# Link Tread with Connector

[See 3D-model](./link_tread_connector.stl)

## Function

The Link Tread with Connector is a modified tread element that provides a rigid, perpendicular attachment point for mounting blades to the tread system.
It enables controlled blade rotation while transmitting hydrodynamic forces from the blade into the linear tread motion.

This component forms the mechanical interface between the blade, cam follower, and the tread.

---

## Quantity

28 pcs per system

---

## Interfaces

- **Blade**
  - Blade mounts to the connector via the cam follower
  - Provides a fixed perpendicular axis for blade rotation

- **Cam Follower**
  - Connected using a low-friction pin, allowing free rotational movement
  - Transfers cam-controlled motion to blade orientation

- **Link Tread**
  - Integrated into the continuous tread chain
  - Maintains full compatibility with adjacent standard tread links

---

## LEGO Reference Parts

- [**3873** Technic Chain Tread 2.5 Wide](https://library.ldraw.org/parts/7308)  
- [**18654** Technic Beam 1](https://library.ldraw.org/parts/1223)  
- [**3673** Technic Pin](https://library.ldraw.org/parts/6706)

---

## Modifications

- Link tread modified as described in the Link Tread specification
- The Technic Beam 1 is repositioned and mounted on top of the tread’s top-plate surface
- This configuration forms a rigid, perpendicular blade attachment point while maintaining tread continuity

---

## Operating Role

- During the **capture phase**, the connector transmits blade-generated forces directly into the tread
- Allows the blade to rotate freely under cam control without binding
- Maintains consistent blade spacing and alignment along the tread path

---

## Design Notes

- Connector geometry prioritizes stiffness and precise alignment
- Low-friction interfaces reduce mechanical losses and wear
- Modular design allows connector links to be placed only where blades are required

---

## Implementations

- Prototype implementation:
  `models/prototype/parts/link_tread_connector/`

- Production implementation (v1.0):
  `models/1.0/parts/link_tread_connector/`

---

## Licensing

This part is provided for non-commercial use under the
Creative Commons Attribution–NonCommercial–ShareAlike 4.0 (CC BY-NC-SA 4.0) license.

Commercial use requires a separate license.
See the repository root `COMMERCIAL.md` for details.

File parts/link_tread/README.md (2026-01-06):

# Link Tread

[See 3D-model](./link_tread.stl)

## Function

The link tread forms the primary linear power transmission path of the WaterTread system.
It carries the blades around the closed-loop tread path and transfers the hydrodynamically generated forces to the drive gears.

The tread enables multiple blades to engage the water flow simultaneously, converting distributed hydrodynamic forces into continuous mechanical motion.

---

## Quantity

140 pcs per system

---

## Interfaces

- **Blade**
  - Blades are mounted to selected tread elements via Link Tread with Connector components
  - Provides a rigid mounting base while allowing controlled blade rotation

- **Drive Gears (40-Tooth)**
  - The tread engages with paired 40-tooth gears at the front and rear axles
  - Transfers linear tread motion into rotational motion

- **Frame and Guides**
  - The tread is guided along a defined path by the frame, side panels, and center panel
  - Maintains alignment and prevents lateral displacement under load

---

## LEGO Reference Part

- **3873** Technic Chain Tread 2.5 Wide

---

## Modifications

- Reduced tread width to **1L** to allow compact side-by-side spacing
- Added a continuous top-plate surface to form a smooth, closed tread surface when links are joined and aligned in the horizontal (capture) position
- The modified top plate reduces water leakage between adjacent blades during the capture phase
- Modified geometry improves hydrodynamic efficiency while maintaining mechanical engagement

---

## Operating Role

- During the **capture phase**, the tread transmits blade-generated forces to the drive gears
- During the **return phase**, the tread carries blades upstream through a protected, low-drag path
- Continuous motion of the tread provides smooth torque delivery to the generator

---

## Design Notes

- The tread is designed for submerged operation and continuous cyclic loading
- Link geometry prioritizes strength, alignment stability, and low friction
- Modularity allows tread length to be adjusted by changing link count

---

## Implementations

- Prototype implementation:
  `models/prototype/parts/link_tread/`

- Production implementation (v1.0):
  `models/1.0/parts/link_tread/`

---

## Licensing

This part is provided for non-commercial use under the
Creative Commons Attribution–NonCommercial–ShareAlike 4.0 (CC BY-NC-SA 4.0) license.

Commercial use requires a separate license.
See the repository root `COMMERCIAL.md` for details.

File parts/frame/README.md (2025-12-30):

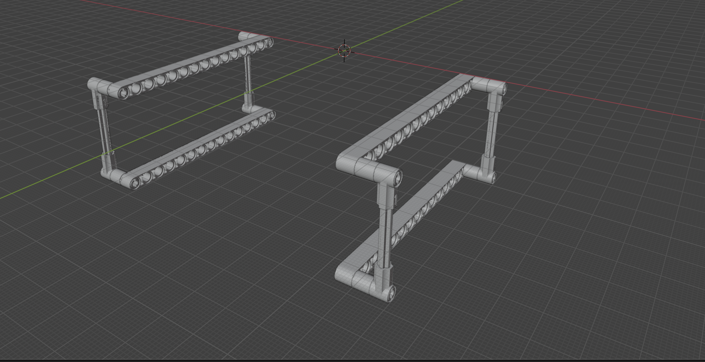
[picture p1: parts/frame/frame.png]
Frame


# Frame

## Function

The frame is the primary structural body of the WaterTread system.
It supports all major components, maintains the fixed spatial relationship between subsystems, and provides the structural reference for alignment of the tread assemblies, axles, gears, and hydrodynamic panels.

The frame defines the overall geometry, rigidity, and transportability of the system.

---

## Quantity

1 pc per system

---

## Interfaces

- **Axle Mounts**
  - Front axle mounts are rigidly fixed to the frame
  - Rear axle mounts interface with the frame via spring-loaded mechanisms for tread tensioning

- **Hydrodynamic Panels**
  - Side panels and center panel are mounted directly to the frame
  - Frame provides sealing surfaces and structural support

- **Cam**
  - Cam elements are positioned relative to the frame via the side panels
  - Ensures repeatable blade orientation timing

- **Flow Diverter**
  - Upstream flow-diverting structures are integrated or attached to the frame

---

## Geometry Description

- Frame geometry follows the closed-loop path of the tread system
- Designed to enclose the active capture region while protecting the return path
- Structural members are arranged to minimize flow obstruction while maintaining stiffness

---

## Transport and Deployment

- The frame is dimensioned to fit within a standard ISO shipping container
- Modular construction may allow disassembly or folding for transport
- Containerized sizing enables simplified logistics and deployment

---

## Design Notes

- Frame stiffness is critical for maintaining gear alignment and reducing wear
- Materials should be selected for submerged or partially submerged operation
- Corrosion resistance and fatigue life are key considerations
- Frame geometry may evolve between system versions while maintaining interface consistency

---

## Implementations

- Prototype implementation:
  `models/prototype/parts/frame/`

- Production implementation (v1.0):
  `models/1.0/parts/frame/`

---

## Licensing

This part is provided for non-commercial use under the
Creative Commons Attribution–NonCommercial–ShareAlike 4.0 (CC BY-NC-SA 4.0) license.

Commercial use requires a separate license.
See the repository root `COMMERCIAL.md` for details.

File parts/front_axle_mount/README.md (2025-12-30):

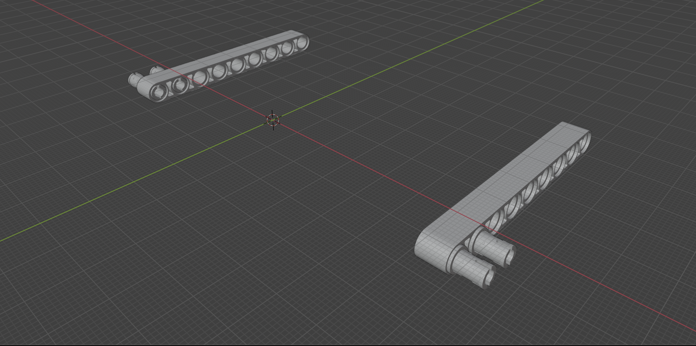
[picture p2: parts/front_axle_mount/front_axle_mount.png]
Front Axle Mount


# Front Axle Mount

## Function

The front axle mount secures the front axle to the frame and provides precise bearing support for rotational motion.
It maintains accurate alignment of the axle, gears, and tread system while minimizing friction and mechanical losses.

The front axle mount is rigidly fixed and does not allow axial movement.

---

## Quantity

2 pcs per system (one per side)

---

## Interfaces

- **Axle**
  - Supports the front axle shaft
  - Maintains fixed axial and radial positioning

- **Frame**
  - Mount is rigidly attached to the frame
  - Defines the fixed reference position for the front axle

- **Gear**
  - Ensures correct gear meshing and alignment under load

---

## Reference Configuration

- Typically implemented as a pillow block bearing assembly
- Bearing type and size are implementation-specific
- Prototype versions may use standard modular bearing blocks

---

## Operating Role

- Provides low-friction rotational support for the front axle
- Maintains precise gear alignment during power transmission
- Serves as the fixed anchor point for the tread system geometry

---

## Design Notes

- Front axle mount rigidity directly affects drivetrain efficiency and durability
- Bearing selection should consider submerged or splash-zone operation
- Mount geometry should allow easy installation and maintenance

---

## Implementations

- Prototype implementation:
  `models/prototype/parts/front_axle_mount/`

- Production implementation (v1.0):
  `models/1.0/parts/front_axle_mount/`

---

## Licensing

This part is provided for non-commercial use under the
Creative Commons Attribution–NonCommercial–ShareAlike 4.0 (CC BY-NC-SA 4.0) license.

Commercial use requires a separate license.
See the repository root `COMMERCIAL.md` for details.

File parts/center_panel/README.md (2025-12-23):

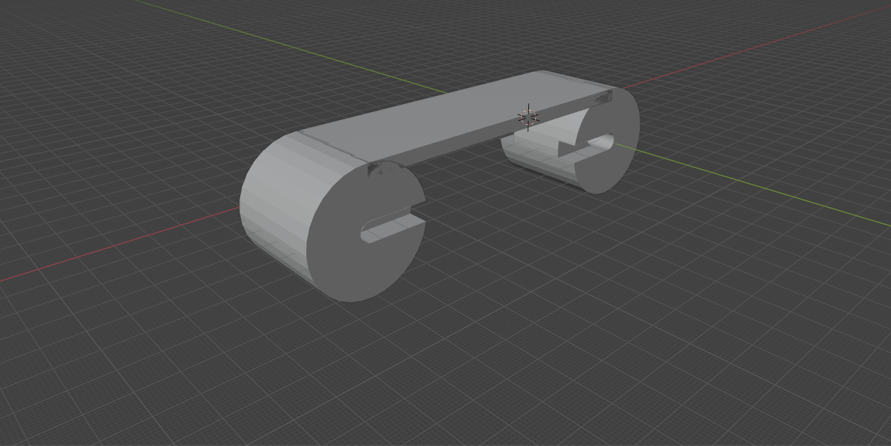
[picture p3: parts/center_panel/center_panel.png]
Center Panel


# Hydrodynamic Center Panel

## Function

The hydrodynamic center panel forms the vertical boundary of the water flow channel beneath the blades.
It prevents vertical water escape, directs incoming flow toward the blade capture region, and improves overall energy transfer efficiency.

Together with the side panels, the center panel defines a controlled hydrodynamic channel through the active capture zone.

---

## Quantity

1 pc per system

---

## Interfaces

- **Frame**
  - Center panel is rigidly mounted to the frame
  - Provides structural continuity along the tread path

- **Blades**
  - Blades operate above the center panel
  - Panel isolates the return path from the incoming flow

- **Hydrodynamic Side Panels**
  - Interfaces with both side panels to form a closed channel
  - Ensures consistent channel geometry across the capture region

- **Axles**
  - Panel geometry accommodates axle passages and clearances

---

## Geometry Description

- The center panel follows the cam rail and tread path geometry
- At the **front axle**, the panel forms a full circular enclosure around the axle
- At the **rear axle**, the panel forms a partial enclosure covering approximately one quarter of the axle circumference
- This geometry allows controlled flow guidance while maintaining mechanical clearance

---

## Operating Role

- During the **capture phase**, the center panel directs flow upward into the blade array
- During the **return phase**, it shields the return path from incoming flow, reducing drag and losses

---

## Design Notes

- Fixed geometry reduces moving mass and mechanical complexity
- Panel shape may be refined to optimize flow acceleration and pressure distribution
- Structural stiffness is required to maintain consistent channel dimensions
- Surface finish may influence hydrodynamic performance

---

## Implementations

- Prototype implementation:
  `models/prototype/parts/center_panel/`

- Production implementation (v1.0):
  `models/1.0/parts/center_panel/`

---

## Licensing

This part is provided for non-commercial use under the
Creative Commons Attribution–NonCommercial–ShareAlike 4.0 (CC BY-NC-SA 4.0) license.

Commercial use requires a separate license.
See the repository root `COMMERCIAL.md` for details.

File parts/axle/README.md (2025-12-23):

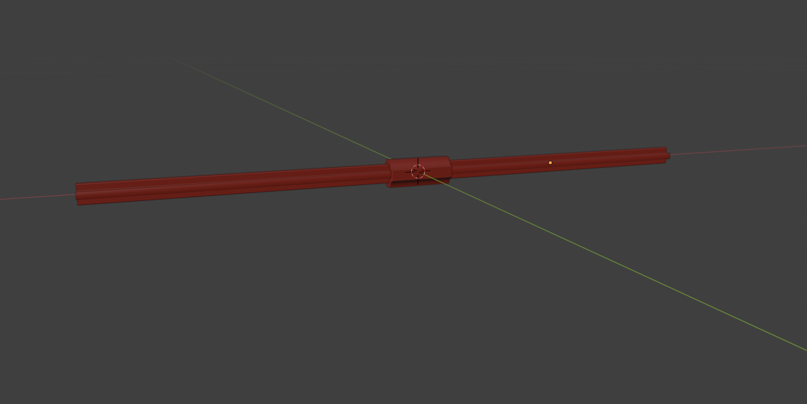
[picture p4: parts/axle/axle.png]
Axle


# Axle

## Function

The axle provides a rigid rotational connection between paired gears and ensures synchronized motion between parallel tread assemblies.
It transmits torque generated by the tread system and maintains precise alignment of rotating components under load.

Axles are critical structural and functional elements of the power transmission system.

---

## Quantity

2 pcs per system

- Front axle (drive and synchronization)
- Rear axle (drive, synchronization, and tensioning interface)

---

## Interfaces

- **Gear**
  - Each axle carries a pair of gears mounted in parallel
  - Ensures both left and right tread paths rotate in unison

- **Axle Mounts**
  - Axle is supported by front or rear axle mounts (bearing blocks)
  - Maintains alignment and minimizes friction

- **Frame**
  - Axle position is fixed or guided relative to the frame
  - Defines tread spacing and geometry

- **Pinion / Generator (Front Axle)**
  - Front axle interfaces with the pinion and generator system

---

## Reference Geometry

- Axle length and diameter are implementation-specific
- Prototype versions may use modular axle segments
- Production versions may use continuous shafts optimized for strength and corrosion resistance

---

## LEGO Reference Parts (Prototype)

- [**59443** Technic Axle Joiner](https://library.ldraw.org/parts/10458)
- [**3737** Technic Axle 10](https://library.ldraw.org/parts/6803)

Reference parts are used for prototyping only and do not constrain production geometry.

---

## Operating Role

- Transfers rotational energy from the tread-driven gears
- Maintains synchronized rotation across both tread assemblies
- Provides a stable axis for power extraction and transmission

---

## Design Notes

- Axle stiffness directly affects gear alignment and wear
- Material selection should account for submerged operation
- Rear axle may allow limited axial movement when integrated with a spring-loaded axle mount for tread tensioning

---

## Implementations

- Prototype implementation:
  `models/prototype/parts/axle/`

- Production implementation (v1.0):
  `models/1.0/parts/axle/`

---

## Licensing

This part is provided for non-commercial use under the
Creative Commons Attribution–NonCommercial–ShareAlike 4.0 (CC BY-NC-SA 4.0) license.

Commercial use requires a separate license.
See the repository root `COMMERCIAL.md` for details.

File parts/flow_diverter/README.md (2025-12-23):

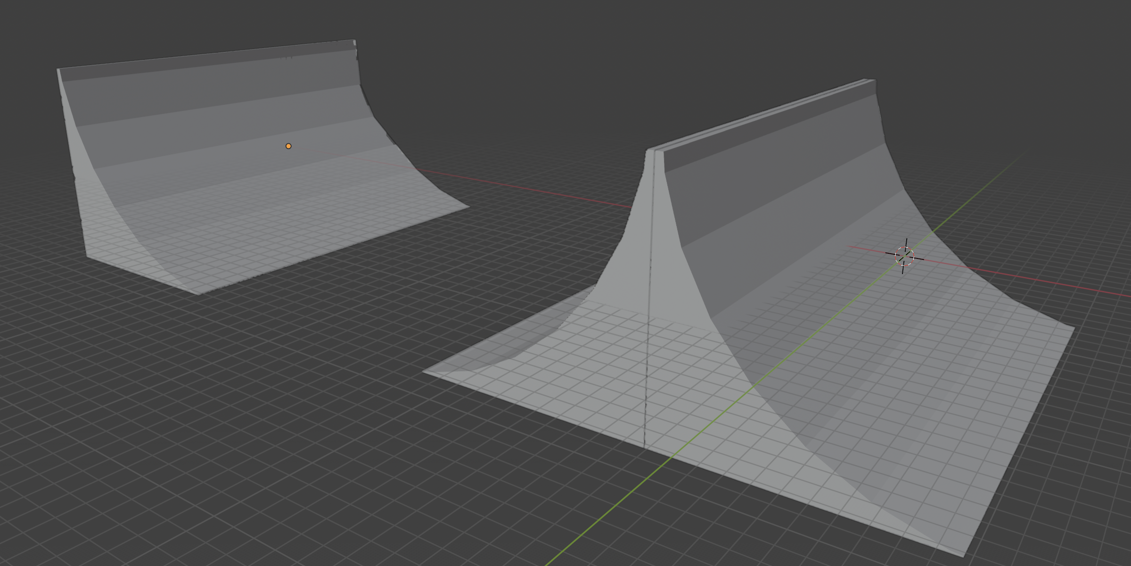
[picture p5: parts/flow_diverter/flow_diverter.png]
Flow Diverter


# Flow Diverter

## Function

The flow diverter is a fixed upstream structure that redirects incoming water toward the upper capture region of the tread system.
Its primary purpose is to prevent flow from entering the lower return path, where it would otherwise cause unnecessary hydrodynamic drag and energy loss.

By guiding water over the active blade region, the flow diverter improves overall system efficiency.

---

## Quantity

1 pc per system

---

## Interfaces

- **Frame**
  - Flow diverter is rigidly mounted to or integrated with the frame
  - Defines the upstream boundary of the hydrodynamic channel

- **Hydrodynamic Panels**
  - Works in conjunction with the side and center panels
  - Completes the upstream flow guidance geometry

- **Incoming Water Flow**
  - Positioned upstream of the tread system
  - Redirects flow vertically and laterally toward the blade capture zone

---

## Geometry Description

- Geometry is shaped to smoothly redirect incoming flow upward
- Leading surfaces are contoured to minimize turbulence and separation
- The diverter may take the form of:
  - A curved plate
  - A wedge-shaped guide
  - A cast or molded mass integrated into the structure

Exact geometry is implementation-specific and may vary with deployment conditions.

---

## Operating Role

- During operation, the flow diverter ensures that the majority of incoming water interacts with blades in the capture phase
- Prevents flow from impinging on blades in the return phase
- Reduces parasitic drag and improves net power output

---

## Design Notes

- Flow diverter is a static, non-moving component
- Structural robustness is prioritized over minimal mass
- Surface finish and curvature may be optimized to reduce losses
- In some deployments, the diverter may also serve a protective role against debris

---

## Implementations

- Prototype implementation:
  `models/prototype/parts/flow_diverter/`

- Production implementation (v1.0):
  `models/1.0/parts/flow_diverter/`

---

## Licensing

This part is provided for non-commercial use under the
Creative Commons Attribution–NonCommercial–ShareAlike 4.0 (CC BY-NC-SA 4.0) license.

Commercial use requires a separate license.
See the repository root `COMMERCIAL.md` for details.

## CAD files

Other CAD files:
models/prototype/prototype_wip.stl
parts/blade/blade.stl
parts/cam/cam.stl
parts/cam_follower/angle.stl
parts/cam_pin/cam_pin.stl
parts/gear/gear.stl
parts/generator/2445.stl
parts/link_tread/link_tread.stl
parts/link_tread_connector/link_tread_connector.stl
parts/pinion/pinion.stl
parts/rear_axle_mount/rear_axle_mount.stl
parts/side_panel/side_panel.stl
parts/cam_follower/cam_follower.stl
parts/pinion/pinion_axle.stl
parts/generator/24316.stl
parts/generator/21980.stl
models/prototype/flow_diverter.blend
models/prototype/prototype_moving_parts.blend
models/prototype/prototype_static_parts.blend
models/prototype/prototype_wip.blend
parts/axle/axle.blend
parts/blade/blade.blend
parts/cam/cam.blend
parts/cam_follower/angle.blend
parts/cam_follower/cam_follower.blend
parts/cam_pin/cam_pin.blend
parts/flow_diverter/flow_diverter.blend
parts/gear/gear.blend
parts/link_tread/link_tread.blend
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

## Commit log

2025-12-23 Add README for Link Tread with Connector
    This README provides detailed information about the Link Tread with Connector, including its function, interfaces, modifications, and licensing.
2025-12-23 Add README for gear component with detailed specifications
    This README provides detailed information about the gear's function, quantity, interfaces, reference geometry, modifications, operating role, design notes, implementations, and licensing.
2025-12-23 Update gear and pinion links in README
2025-12-23 Add README for axle component documentation
    This README provides detailed information about the axle's function, quantity, interfaces, reference geometry, LEGO parts for prototyping, operating role, design notes, implementations, and licensing.
2025-12-23 Add README for frame component of WaterTread system
    Added detailed documentation for the frame component of the WaterTread system, including its function, interfaces, geometry, transport considerations, design notes, implementations, and licensing.
2025-12-23 Add README for Front Axle Mount
    This README provides detailed information about the front axle mount, including its function, quantity, interfaces, reference configuration, operating role, design notes, implementations, and licensi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
2025-12-23 Add README for rear axle mount
    Added detailed documentation for the rear axle mount, including its function, quantity, interfaces, reference configuration, operating role, design notes, implementations, and licensing information.
2025-12-23 Add README for Flow Diverter component
    Added detailed documentation for the flow diverter component, including its function, quantity, interfaces, geometry, operating role, design notes, implementations, and licensing.
2025-12-23 Add image to Flow Diverter README
2025-12-23 Add image to axle README
2025-12-23 Add image to gear README
2025-12-23 Update LEGO reference link for Technic Gear 40 Tooth
2025-12-23 Update LEGO parts count and modification descriptions
    Updated the number of Technic Axle Joiners and modified the description of the modifications for clarity.
2025-12-24 Add image to Link Tread Connector README
2025-12-25 Add power transmission overview documentation
    Added an overview of power transmission mechanics and drivetrain design.
2025-12-27 Add LEGO Technic reference to rear axle mount README
    Added LEGO Technic reference part information to README.
2025-12-30 Add image to frame README
2025-12-30 Add image to Front Axle Mount README
2025-12-30 Add image to Rear Axle Mount README
2025-12-30 Remove axle information from frame README
    Removed details about axles from the README.
2026-01-06 Correct link name for Link Tread Connector
2026-01-06 Add LFS tracking for STL and Blender files
2026-01-06 Add Prototype (WIP)
    [prototype_wip.blend, prototype_wip.stl]
2026-01-06 update gear
    [gear.blend, gear.stl]
2026-01-06 Update 3D model link in README for gear
2026-01-06 update gears
    [prototype_wip.blend, prototype_wip.stl]
2026-01-06 Add link to 3D model in README
    Added a link to the 3D model of the prototype.
2026-01-06 update prototype
    [prototype_wip.blend]
2026-01-06 update to rear axle mount
    [prototype_wip.blend, rear_axle_mount.blend, rear_axle_mount.stl]
2026-01-06 updated blade
    [blade.blend, blade.stl, prototype_wip.blend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]
2026-01-08 Cam Follower etc.
    [cam_follower.blend, cam_follower.stl, prototype_wip.blend]
2026-01-08 updade cam
    [cam.blend, cam.stl]
2026-01-08 update model
    [prototype_wip.blend]
2026-01-08 cleanup model
    [prototype_wip.blend, prototype_wip.stl]
2026-01-08 clean and add glb
    [prototype_wip.blend]
2026-01-08 latest version
    [prototype_wip.blend, prototype_wip.stl]
2026-01-12 update models
    [prototype_wip.blend, prototype_wip.stl]
2026-01-12 update models. add generators.
    [prototype_wip.blend, prototype_wip.stl]
2026-01-12 add parts
    [21980.stl, 24316.stl, 2445.stl]
2026-01-20 update parts
    [gear.blend, gear.stl, prototype_moving_parts.blend]
2026-01-21 update parts and models
    [link_tread.blend, link_tread.stl, pinion.blend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]
2026-01-23 update parts, models, scripts
    [link_tread_connector.blend, link_tread_connector.stl, prototype_moving_parts.blend]
2026-01-25 update models, scripts, some parts
    [cam_pin.blend, cam_pin.stl, prototype_moving_parts.blend]
2026-01-26 fix scripts, models, etc.
    [prototype_moving_parts.blend]
2026-01-31 update parts, script
    [angle.blend, angle.stl, blade.blend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]
2026-01-31 update models and scripts
    [prototype_moving_parts.blend]
2026-02-02 update parts, readme
    [flow_diverter.blend, prototype_moving_parts.blend, prototype_static_parts.blend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]
